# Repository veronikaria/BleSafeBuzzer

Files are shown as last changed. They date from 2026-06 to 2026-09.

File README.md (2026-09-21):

# SafeGuard Buzzer v1 — CR2450 One-Side Assembly

SafeGuard Buzzer is a BLE-controlled backpack or laptop-case alarm module paired with SafeGuard Ping. It uses a passive magnetic sounder so firmware can generate alarm patterns and escalation. KiCad is the source of truth for the electrical and PCB design.

## Current hardware

- BLE module: Renesas/Dialog DA14531MOD-00F01002, LCSC C5360767
- Battery: replaceable CR2450 primary coin cell
- Battery holder: MYOUNG MY-2450-03, LCSC C2988622
- Buzzer: FUET FUET-1365-3V passive magnetic SMD sounder, LCSC C417422
- Power switch: PCM12SMTR, LCSC C221841
- Buzzer driver: AO3400A N-channel MOSFET, LCSC C20917
- Clamp diode: BAT54WS, LCSC C22629
- Status indicator: red 0603 LED with 2.2 kΩ resistor
- Debug: compact VCC, GND, SWDIO, and SWCLK pads
- Current measurement: bridgeable JP1 link
- No charger, USB, user silence/test button, or external reset supervisor

Power path:

```text
CR2450 -> S1 ON/OFF switch -> JP1 current-measurement bridge -> VCC
```

Buzzer drive path:

```text
DA14531MOD PWM/GPIO -> 100 ohm gate resistor -> AO3400A -> passive buzzer
                                      |
                                  100 kohm pulldown
```

## Mechanical configuration

- Board size: 65.0 × 40.0 mm
- BT1: Top at `(24.0, 24.0)`
- BZ1: Top at `(48.0, 31.0)`, near the edge for a future hidden acoustic opening
- S1: Top at `(6.0, 7.0)`, left-edge accessible
- U1: Top at `(54.5, 10.5)`, with the antenna at the board edge
- All 13 assembled BOM/CPL components are on Top
- Bottom contains copper and traces only; it has no assembled components or footprints
- Battery metal does not overlap the DA14531MOD antenna keepout

The PCB remains a two-copper-layer design, but JLC assembly is **Top Side only**.

## Active KiCad files

- Schematic: `SafeGuardBuzzer_v1.kicad_sch`
- PCB: `SafeGuardBuzzer_v1.kicad_pcb`
- Project-local footprints: `SafeGuardBuzzer_Local.pretty/`
- Project-local symbols: `SafeGuardBuzzer_Local.kicad_sym`

## Validation status

- ERC: 0 errors and 10 footprint-library configuration warnings
- DRC: 0 real electrical or fabrication errors
- Unconnected items: 0
- Shorts: 0
- Clearance errors: 0
- Antenna-keepout violations: 0
- Remaining DRC warnings: missing configured stock footprint libraries, one U1 library-copy mismatch, and two clipped-silkscreen warnings
- Schematic parity warnings are metadata/value differences and do not change connectivity or the verified manufacturing BOM/CPL

## JLC manufacturing outputs

Output folder:

```text
Manufacturing_Final_Buzzer_v1_CR2450_OneSide_JLC/
```

Upload these files:

- Gerber/drill ZIP: `SafeGuardBuzzer_v1_CR2450_OneSide_JLC_Gerber_Drill_Upload_CORRECTED.zip`
- BOM: `SafeGuardBuzzer_v1_CR2450_OneSide_JLC_BOM.csv`
- CPL: `SafeGuardBuzzer_v1_CR2450_OneSide_JLC_CPL.csv`

Do not upload `SafeGuardBuzzer_v1_CR2450_OneSide_JLC_Gerber_Drill_Upload.zip`. That older archive contains `SafeGuardBuzzer_v1-drl_map.gbr`, whose legend extends outside the PCB and can cause JLCPCB to report an incorrect 75 × 70 mm size.

The corrected ZIP contains only the fabrication Gerbers, the actual Excellon drill file, and the Gerber job file. Its Edge.Cuts profile is exactly 65 × 40 mm.

J1, J2, and JP1 are copper-only debug/test/current-measurement pads and are intentionally excluded from both BOM and CPL.

## JLC order settings and preview checklist

1. Select a two-layer PCB.
2. Select **Top Side only** assembly.
3. Confirm detected board size is 65 × 40 mm.
4. Confirm all 13 CPL placements are Top; Bottom should contain no placements.
5. Do not accept automatic component alignment if the uploaded CPL already overlays the Gerbers correctly.
6. Confirm BT1 is MY-2450-03 / C2988622, BZ1 is FUET-1365-3V / C417422, S1 is PCM12SMTR / C221841, and U1 is DA14531MOD / C5360767.
7. Confirm buzzer, diode, LED, MOSFET, switch, and module orientation in the placement preview.
8. Confirm the DA14531MOD antenna keepout remains free of copper and battery metal.

## Prototype note

CR2450 cells have less pulse-current capability than CR123A cells. The selected buzzer and bulk capacitance are intended for a moderate alarm, but sound pressure and battery droop should be measured on assembled prototypes during a full one-to-two-minute alarm cycle.

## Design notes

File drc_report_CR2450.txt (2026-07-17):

** Drc report for SafeGuardBuzzer_v1.kicad_pcb **
** Created on 2026-07-14T22:43:08-0600 **

** Found 10 DRC violations **
[lib_footprint_issues]: The current configuration does not include the footprint library 'Resistor_SMD'.
    Local override; warning
    @(81.0000 mm, 8.0000 mm): Footprint R1
[lib_footprint_issues]: The current configuration does not include the footprint library 'Capacitor_SMD'.
    Local override; warning
    @(63.5000 mm, 20.5000 mm): Footprint C2
[lib_footprint_issues]: The current configuration does not include the footprint library 'LED_SMD'.
    Local override; warning
    @(84.2000 mm, 8.0000 mm): Footprint D1
[lib_footprint_issues]: The current configuration does not include the footprint library 'Button_Switch_SMD'.
    Local override; warning
    @(7.0000 mm, 7.0000 mm): Footprint S1
[lib_footprint_issues]: The current configuration does not include the footprint library 'Resistor_SMD'.
    Local override; warning
    @(88.4000 mm, 37.8000 mm): Footprint R3
[lib_footprint_issues]: The current configuration does not include the footprint library 'Capacitor_SMD'.
    Local override; warning
    @(58.0000 mm, 22.2000 mm): Footprint C1
[lib_footprint_issues]: The current configuration does not include the footprint library 'Diode_SMD'.
    Local override; warning
    @(86.0000 mm, 43.0000 mm): Footprint D2
[lib_footprint_issues]: The current configuration does not include the footprint library 'Package_TO_SOT_SMD'.
    Local override; warning
    @(86.5000 mm, 33.0000 mm): Footprint Q1
[lib_footprint_issues]: The current configuration does not include the footprint library 'Resistor_SMD'.
    Local override; warning
    @(78.0000 mm, 10.5000 mm): Footprint R2
[lib_footprint_issues]: The current configuration does not include the footprint library 'Capacitor_SMD'.
    Local override; warning
    @(53.0000 mm, 22.2000 mm): Footprint C3

** Found 0 unconnected pads **

** Found 14 Footprint errors **
[footprint_symbol_mismatch]: Value (BZ1) doesn't match symbol value (FUET-1365-3V).
    Local override; warning
    @(75.0000 mm, 34.0000 mm): Footprint BZ1
[footprint_symbol_mismatch]: Value (C1) doesn't match symbol value (10uF).
    Local override; warning
    @(58.0000 mm, 22.2000 mm): Footprint C1
[footprint_symbol_mismatch]: Value (C2) doesn't match symbol value (100nF).
    Local override; warning
    @(63.5000 mm, 20.5000 mm): Footprint C2
[footprint_symbol_mismatch]: Value (C3) doesn't match symbol value (100uF).
    Local override; warning
    @(53.0000 mm, 22.2000 mm): Footprint C3
[footprint_symbol_mismatch]: Value (D1) doesn't match symbol value (Red LED).
    Local override; warning
    @(84.2000 mm, 8.0000 mm): Footprint D1
[footprint_symbol_mismatch]: Value (D2) doesn't match symbol value (BAT54WS).
    Local override; warning
    @(86.0000 mm, 43.0000 mm): Footprint D2
[footprint_symbol_mismatch]: Value (J1) doesn't match symbol value (SWD_DEBUG).
    Local override; warning
    @(69.0000 mm, 23.5000 mm): Footprint J1
[footprint_symbol_mismatch]: Footprint attributes don't match symbol: 'Exclude from bill of materials' settings differ.
    Local override; warning
    @(69.0000 mm, 23.5000 mm): Footprint J1
[footprint_symbol_mismatch]: Value (J2) doesn't match symbol value (VBAT_GND_TEST).
    Local override; warning
    @(21.0000 mm, 10.0000 mm): Footprint J2
[footprint_symbol_mismatch]: Footprint attributes don't match symbol: 'Exclude from bill of materials' settings differ.
    Local override; warning
    @(21.0000 mm, 10.0000 mm): Footprint J2
[footprint_symbol_mismatch]: Value (JP1) doesn't match symbol value (CURRENT_MEAS).
    Local override; warning
    @(27.0000 mm, 8.0000 mm): Footprint JP1
[footprint_symbol_mismatch]: Footprint attributes don't match symbol: 'Exclude from bill of materials' settings differ.
    Local override; warning
    @(27.0000 mm, 8.0000 mm): Footprint JP1
[footprint_symbol_mismatch]: Value (Q1) doesn't match symbol value (AO3400A).
    Local override; warning
    @(86.5000 mm, 33.0000 mm): Footprint Q1
[footprint_symbol_mismatch]: Value (S1) doesn't match symbol value (PCM12 ON/OFF).
    Local override; warning
    @(7.0000 mm, 7.0000 mm): Footprint S1

** End of Report **

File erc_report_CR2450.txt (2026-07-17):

ERC report (2026-07-14T22:45:45-0600, Encoding UTF8)

***** Sheet /
[footprint_link_issues]: The current configuration does not include the footprint library 'Button_Switch_SMD'.
    ; warning
    @(59.69 mm, 44.45 mm): Symbol S1 [SW_SPDT_PCM12_Power]
[footprint_link_issues]: The current configuration does not include the footprint library 'Capacitor_SMD'.
    ; warning
    @(44.45 mm, 74.93 mm): Symbol C1 [C]
[footprint_link_issues]: The current configuration does not include the footprint library 'Capacitor_SMD'.
    ; warning
    @(44.45 mm, 82.55 mm): Symbol C2 [C]
[footprint_link_issues]: The current configuration does not include the footprint library 'Capacitor_SMD'.
    ; warning
    @(44.45 mm, 91.44 mm): Symbol C3 [C]
[footprint_link_issues]: The current configuration does not include the footprint library 'Resistor_SMD'.
    ; warning
    @(69.85 mm, 110.49 mm): Symbol R2 [R]
[footprint_link_issues]: The current configuration does not include the footprint library 'Diode_SMD'.
    ; warning
    @(69.85 mm, 128.27 mm): Symbol D2 [Diode_Schottky]
[footprint_link_issues]: The current configuration does not include the footprint library 'Package_TO_SOT_SMD'.
    ; warning
    @(85.09 mm, 119.38 mm): Symbol Q1 [NMOS_GDS]
[footprint_link_issues]: The current configuration does not include the footprint library 'Resistor_SMD'.
    ; warning
    @(85.09 mm, 132.08 mm): Symbol R3 [R]
[footprint_link_issues]: The current configuration does not include the footprint library 'Resistor_SMD'.
    ; warning
    @(129.54 mm, 119.38 mm): Symbol R1 [R]
[footprint_link_issues]: The current configuration does not include the footprint library 'LED_SMD'.
    ; warning
    @(144.78 mm, 119.38 mm): Symbol D1 [LED_Red_0603]

 ** ERC messages: 10  Errors 0  Warnings 10

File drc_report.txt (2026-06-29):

** Drc report for SafeGuardBuzzer_v1.kicad_pcb **
** Created on 2026-06-28T23:07:18-0600 **

** Found 0 DRC violations **

** Found 0 unconnected pads **

** Found 0 Footprint errors **

** End of Report **

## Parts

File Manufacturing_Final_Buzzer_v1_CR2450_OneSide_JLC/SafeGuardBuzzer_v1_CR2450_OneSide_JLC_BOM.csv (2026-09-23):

Comment | Designator | Footprint | LCSC Part # | MPN | Quantity
MYOUNG MY-2450-03 CR2450 holder | BT1 | BatteryHolder_MYOUNG_MY-2450-03_C2988622_CR2450 | C2988622 | MY-2450-03 | 1
FUET-1365-3V passive buzzer | BZ1 | Buzzer_FUET_FUET-1365-3V_C417422 | C417422 | FUET-1365-3V | 1
10uF 0805 capacitor | C1 | C_0805_2012Metric | C440198 | GRM21BR61H106KE43L | 1
100nF 0603 capacitor | C2 | C_0603_1608Metric | C14663 | CC0603KRX7R9BB104 | 1
100uF 1210 capacitor | C3 | C_1210_3225_Samsung_CL32A107MQVNNNE_C49066 | C49066 | CL32A107MQVNNNE | 1
Red LED 0603 | D1 | LED_0603_1608Metric | C2286 | KT-0603R | 1
BAT54WS Schottky diode | D2 | D_SOD-323 | C22629 | BAT54WS L9 | 1
AO3400A N-MOSFET | Q1 | SOT-23 | C20917 | AO3400A | 1
2.2k 0603 resistor | R1 | R_0603_1608Metric | C4190 | 0603WAF2201T5E | 1
100 ohm 0603 resistor | R2 | R_0603_1608Metric | C22775 | 0603WAF1000T5E | 1
100k 0603 resistor | R3 | R_0603_1608Metric | C25803 | 0603WAF1003T5E | 1
PCM12SMTR ON/OFF slide switch | S1 | SW_SPDT_PCM12 | C221841 | PCM12SMTR | 1
DA14531MOD-00F01002 BLE module | U1 | XCVR_DA14531MOD-00F01002 | C5360767 | DA14531MOD-00F01002 | 1

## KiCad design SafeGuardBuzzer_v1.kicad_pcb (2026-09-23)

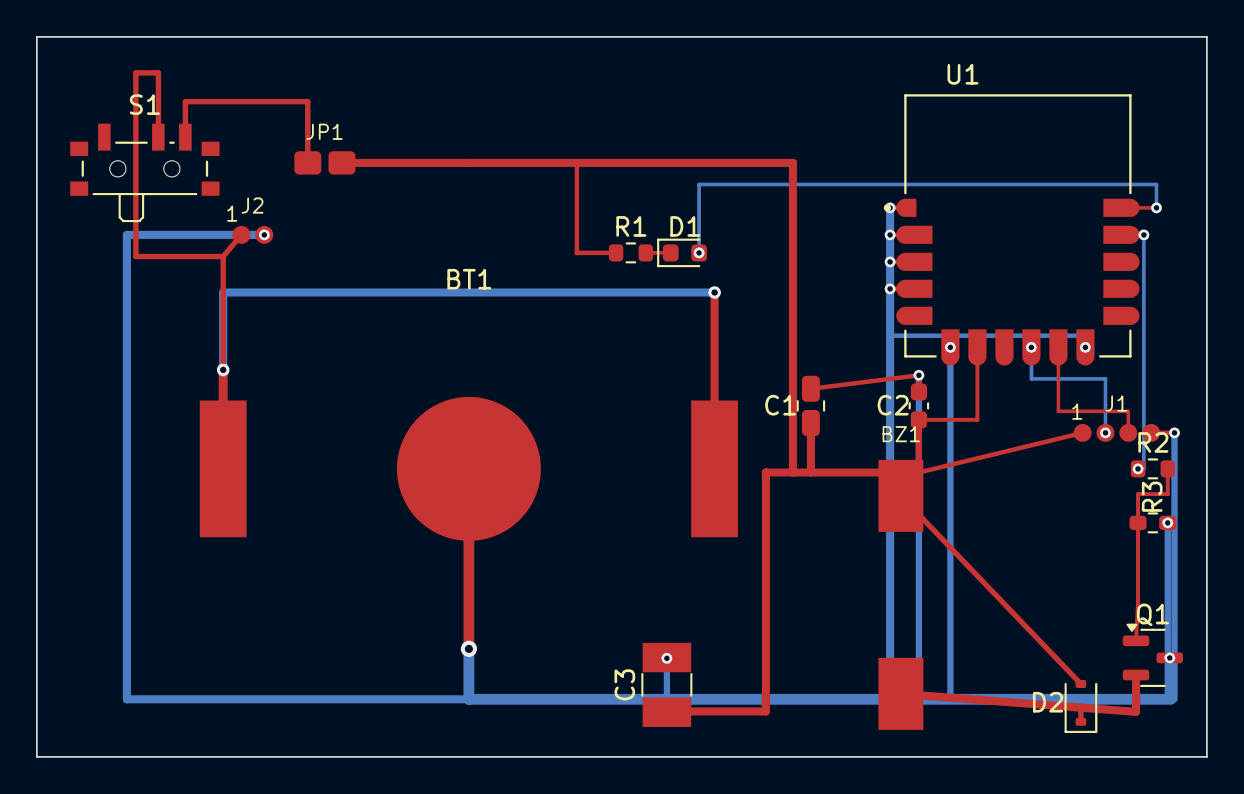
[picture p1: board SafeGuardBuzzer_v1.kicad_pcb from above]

Board: 2 copper layers, 65.0 x 40.0 mm, 16 parts (0 on the bottom side), 11 nets.

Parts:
BT1: MYOUNG MY-2450-03 CR2450 holder; BatteryHolder_MYOUNG_MY-2450-03_C2988622_CR2450
BZ1: FUET-1365-3V; Buzzer_FUET_FUET-1365-3V_C417422
C1: 10uF; C_0805_2012Metric
C2: 100nF; C_0603_1608Metric
C3: 100uF; C_1210_3225_Samsung_CL32A107MQVNNNE_C49066
D1: Red LED; LED_0603_1608Metric
D2: BAT54WS; D_SOD-323
J1: SWD_DEBUG; TP_SWD_1x04_1.27mm_Compact
J2: VBAT_GND_TEST; TP_1x02_1.27mm_Compact
JP1: CURRENT_MEAS; TP_Current_Jumper_2Pad_Compact
Q1: AO3400A; SOT-23
R1: 2.2k; R_0603_1608Metric
R2: 100; R_0603_1608Metric
R3: 100k; R_0603_1608Metric
S1: PCM12 ON/OFF; SW_SPDT_PCM12
U1: DA14531MOD-00F01002; XCVR_DA14531MOD-00F01002

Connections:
BUZZER_NEG: BZ1.2, D2.1, Q1.2
BUZZER_PWM: R2.1, U1.J15
BUZZER_PWM_GATE: Q1.1, R2.2, R3.1
GND: BT1.2, C1.2, C2.2, C3.2, J1.4, J2.2, Q1.3, R3.2, U1.J1, U1.J2, U1.J3, U1.J4, U1.J6, U1.J11
LED_A: D1.1, R1.2
LED_STATUS: D1.2, U1.J16
SWCLK: J1.3, U1.J10
SWDIO: J1.2, U1.J9
VBAT_RAW: BT1.1, J2.1, S1.2
VBAT_SW: JP1.1, S1.3
VCC: BZ1.1, C1.1, C2.1, C3.1, D2.2, J1.1, JP1.2, R1.1, U1.J7

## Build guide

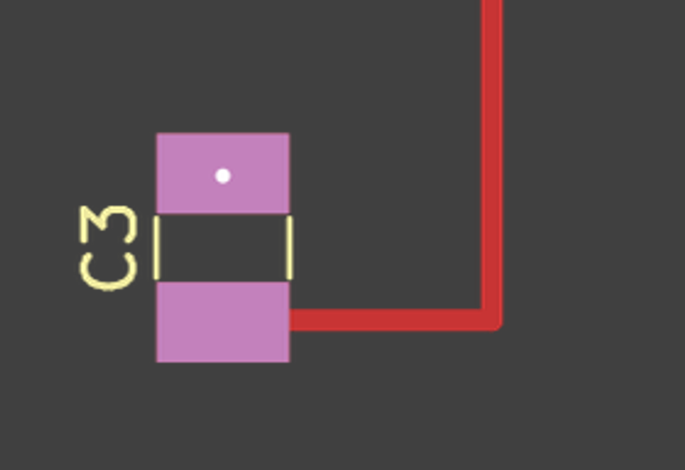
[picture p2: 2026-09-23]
Manufacturing_Final_Buzzer_v1_CR2450_OneSide_JLC/C3_corrected_footprint_closeup.png

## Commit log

2026-06-28 Create SafeGuard Buzzer v1 schematic candidate
    [SafeGuardBuzzer_v1.kicad_sch]
2026-06-29 Resolve Buzzer CR123A holder footprint
    [SafeGuardBuzzer_v1.kicad_sch]
2026-06-29 Create initial Buzzer PCB rough layout candidate
    [SafeGuardBuzzer_v1.kicad_pcb]
2026-06-29 Clean Buzzer RF keepout and DRC before routing
    [SafeGuardBuzzer_v1.kicad_pcb]
2026-06-29 Route initial Buzzer power path
    [SafeGuardBuzzer_v1.kicad_pcb]
2026-06-29 Add Buzzer project footprints and project settings
2026-06-29 Complete Buzzer v1 routing
    [SafeGuardBuzzer_v1.kicad_pcb]
2026-06-29 Generate final Buzzer v1 JLC manufacturing package
    [SafeGuardBuzzer_v1-B_Cu.gbl, SafeGuardBuzzer_v1-B_Mask.gbs, SafeGuardBuzzer_v1-B_Paste.gbp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]
2026-07-09 Update Buzzer JLC BOM metadata and corrected CPL origin
    [SafeGuardBuzzer_v1.kicad_sch, SafeGuardBuzzer_v1_JLC_BOM.csv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]
2026-07-15 Checkpoint before Buzzer CR2450 redesign
    [SafeGuardBuzzer_v1-B_Cu.gbl, SafeGuardBuzzer_v1-B_Mask.gbs, SafeGuardBuzzer_v1-B_Paste.gbp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]
2026-07-17 Redesign Buzzer v1 for CR2450 battery
    [SafeGuardBuzzer_v1-B_Cu.gbl, SafeGuardBuzzer_v1-B_Mask.gbs, SafeGuardBuzzer_v1-B_Paste.gbp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]
2026-09-21 Convert Buzzer CR2450 to one-sided assembly
    [SafeGuardBuzzer_v1-B_Cu.gbl, SafeGuardBuzzer_v1-B_Mask.gbs, SafeGuardBuzzer_v1-B_Paste.gbp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]
2026-09-23 PCB contains copper zones near C3; fixed it
    [SafeGuardBuzzer_v1-B_Cu.gbl, SafeGuardBuzzer_v1-B_Mask.gbs, SafeGuardBuzzer_v1-B_Paste.gbp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]
